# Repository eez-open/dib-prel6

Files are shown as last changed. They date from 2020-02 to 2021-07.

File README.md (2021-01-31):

### Ownership and License
The contributors are listed in CONTRIB.TXT. This project uses the TAPR v1.0 license, see LICENSE.TXT.

OSHW-HR000005 (https://certification.oshwa.org/hr000005.html)

### Description

The EEZ DIB PREL6 module features six independently programmable power relays.

### Feature list

* On-board STM32F030C6T6 or STM32F031C4T6 MCU
* 2 x 16-pin dual row 3.81 mm connectors
* 4 x SPDT relays, max. 8 A / 230 Vac
* 2 x SPST relays, max. 8 A / 230 Vac
* On-board +3.3 V LDO
* Firmware download via UART
* Optional SWD for debugging
* I2C EEPROM for storing board specific parameters
* Dimensions: 146 x 95 mm, 2-layer PCB

### Firmware repository

https://github.com/eez-open/dib-prel6-fw
The firmware download procedure is described in the User Manual in [Chapter 13](https://github.com/eez-open/modular-psu/blob/master/docs/user%20manual/EEZ%20BB3%20user%20manual.pdf). 

### r1B2 prototype

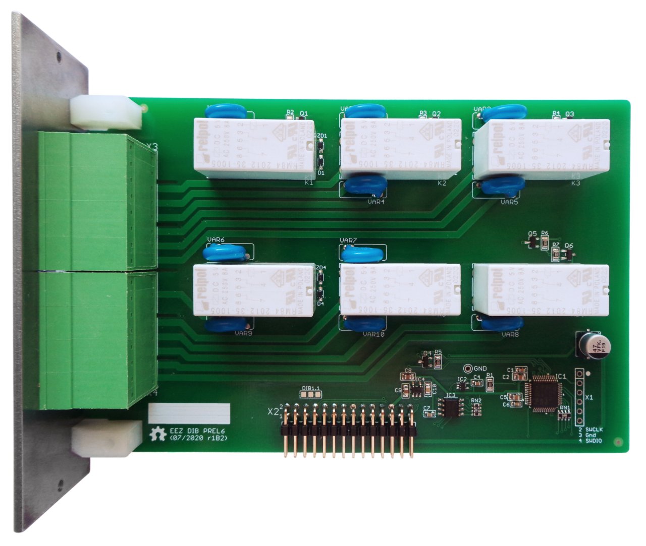
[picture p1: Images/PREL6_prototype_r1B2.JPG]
prototype


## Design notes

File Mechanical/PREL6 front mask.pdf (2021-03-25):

# PREL6

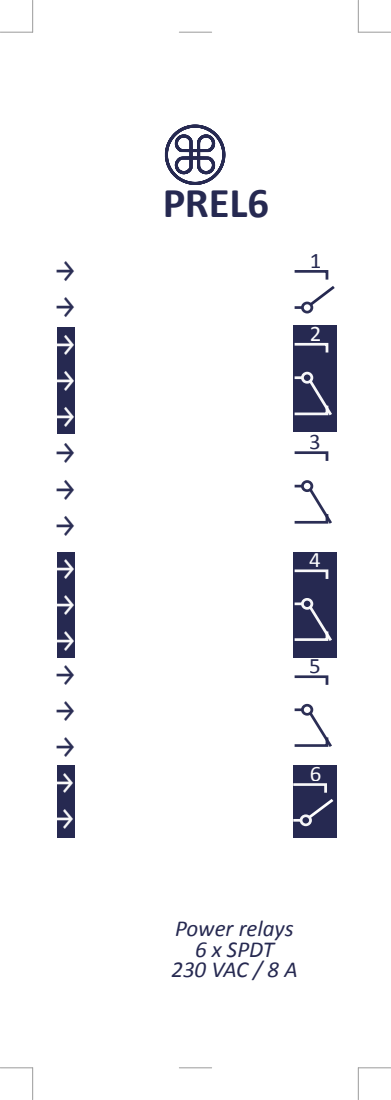
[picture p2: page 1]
Power relays 6 x SPDT 230 VAC / 8 A

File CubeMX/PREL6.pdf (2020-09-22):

## PREL6 Project Configuration Report

# 1. Description

## 1.1. Project

Project Name | PREL6
Board Name | custom
Generated with: | STM32CubeMX 5.6.1
Date | 09/22/2020

## 1.2. MCU

MCU Series | STM32F0
MCU Line | STM32F0x0 Value Line
MCU name | STM32F030C6Tx
MCU Package | LQFP48
MCU Pin number | 48

# 2. Pinout Configuration

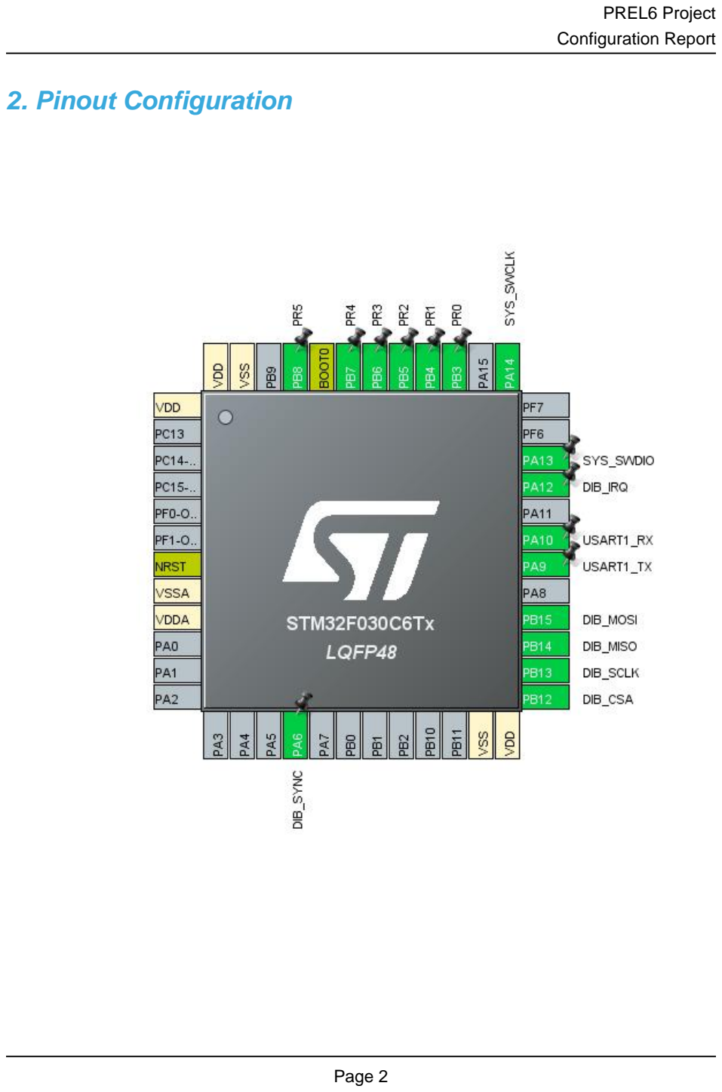
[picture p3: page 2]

# 3. Pins Configuration

Pin Number LQFP48 | Pin Name (function after reset) | Pin Type | Alternate Function(s) | Label
1 | VDD | Power
7 | NRST | Reset
8 | VSSA | Power
9 | VDDA | Power
16 | PA6 * | I/O | GPIO_Input | DIB_SYNC
23 | VSS | Power
24 | VDD | Power
25 | PB12 | I/O | SPI1_NSS | DIB_CSA
26 | PB13 | I/O | SPI1_SCK | DIB_SCLK
27 | PB14 | I/O | SPI1_MISO | DIB_MISO
28 | PB15 | I/O | SPI1_MOSI | DIB_MOSI
30 | PA9 | I/O | USART1_TX
31 | PA10 | I/O | USART1_RX
33 | PA12 * | I/O | GPIO_Output | DIB_IRQ
34 | PA13 | I/O | SYS_SWDIO
37 | PA14 | I/O | SYS_SWCLK
39 | PB3 * | I/O | GPIO_Output | PR0
40 | PB4 * | I/O | GPIO_Output | PR1
41 | PB5 * | I/O | GPIO_Output | PR2
42 | PB6 * | I/O | GPIO_Output | PR3
43 | PB7 * | I/O | GPIO_Output | PR4
44 | BOOT0 | Boot
45 | PB8 * | I/O | GPIO_Output | PR5
47 | VSS | Power
48 | VDD | Power

## * The pin is affected with an I/O function

# 4. Clock Tree Configuration

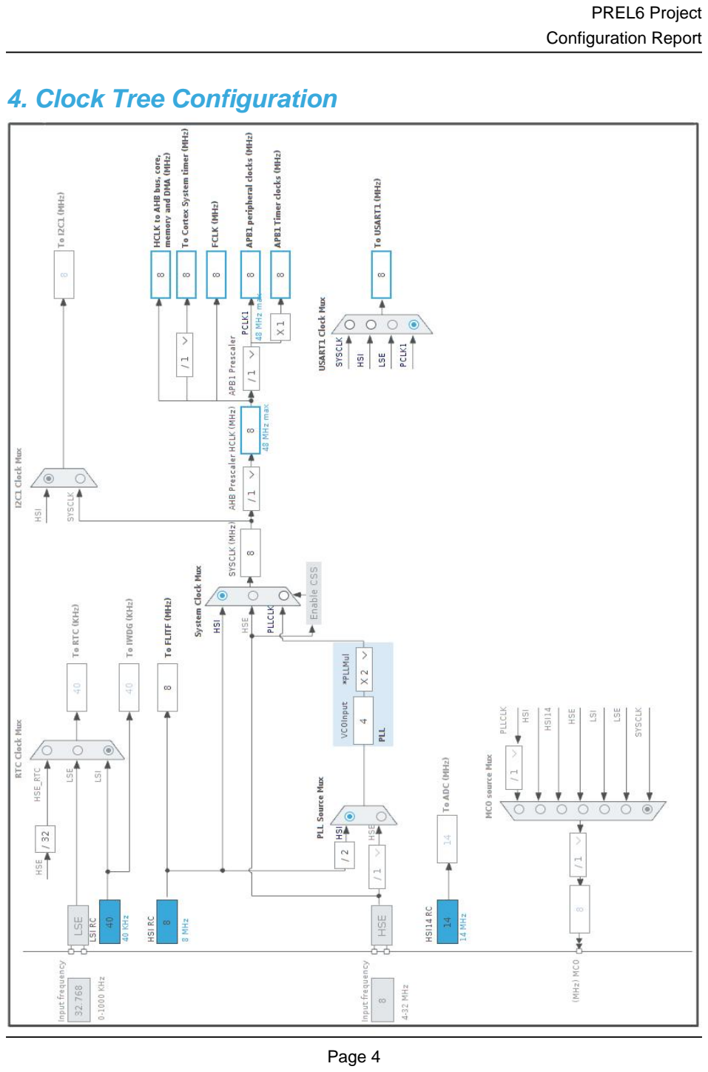
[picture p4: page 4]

# 5. Software Project

## 5.1. Project Settings

Name | Value
Project Name | PREL6
Project Folder | /home/denis/BACKUP/EEZ/Digital control/MCU/STM32/Projects/PREL6
Toolchain / IDE | EWARM V8.32
Firmware Package Name and Version | STM32Cube FW_F0 V1.11.0

## 5.2. Code Generation Settings

Name | Value
STM32Cube MCU packages and embedded software | Copy all used libraries into the project folder
Generate peripheral initialization as a pair of '.c/.h' files | No
Backup previously generated files when re-generating | No
Delete previously generated files when not re-generated | Yes
Set all free pins as analog (to optimize the power consumption) | No

# 6. Power Consumption Calculator report

### 6.1. Microcontroller Selection

Series | STM32F0
Line | STM32F0x0 Value Line
MCU | STM32F030C6Tx
Datasheet | 024849_Rev2

### 6.2. Parameter Selection

Temperature | 25
Vdd | 3.6

### 6.3. Battery Selection

Battery | Li-SOCL2(A3400)
Capacity | 3400.0 mAh
Self Discharge | 0.08 %/month
Nominal Voltage | 3.6 V
Max Cont Current | 100.0 mA
Max Pulse Current | 200.0 mA
Cells in series | 1
Cells in parallel | 1

## 6.4. Sequence

Step | Step1 | Step2
Mode | RUN | STOP
Vdd | 3.6 | 3.6
Voltage Source | Battery | Battery
Range | No Scale | No Scale
Fetch Type | FLASH | n/a
CPU Frequency | 48 MHz | 0 Hz
Clock Configuration | HSE PLL All IPs ON | Regulator_LP
Clock Source Frequency | 8 MHz | 0 Hz

### Peripherals

Additional Cons. | 0 mA | 0 mA
Average Current | 23.46 mA | 7.9 µA
Duration | 0.1 ms | 0.9 ms
DMIPS | 0.0 | 0.0
Ta Max | 100.36 | 105
Category | In DS Table | In DS Table

## 6.5. RESULTS

Sequence Time | 1 ms | Average Current | 2.35 mA
Battery Life | 1 month, 29 days, 16 hours | Average DMIPS | 0.0 DMIPS

## 6.6. Chart

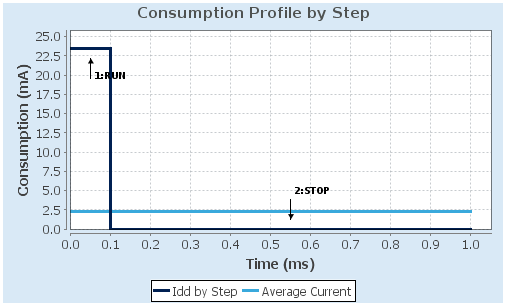
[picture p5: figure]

# 7. IPs and Middleware Configuration

# 7.1. CRC

## mode: Activated 7.1.1. Parameter Settings:

### Basic Parameters:

Default Polynomial State | Enable
Default Init Value State | Enable

### Advanced Parameters:

Input Data Inversion Mode | None
Output Data Inversion Mode | Disable
Input Data Format | Bytes

# 7.2. GPIO

# 7.3. SPI1

## Mode: Full-Duplex Slave Hardware NSS Signal: Hardware NSS Input Signal 7.3.1. Parameter Settings:

### Basic Parameters:

Frame Format | Motorola
Data Size | 4 Bits
First Bit | MSB First

### Clock Parameters:

Clock Polarity (CPOL) | Low
Clock Phase (CPHA) | 1 Edge

### Advanced Parameters:

CRC Calculation | Disabled
NSS Signal Type | Input Hardware

# 7.4. SYS

## mode: Debug Serial Wire Timebase Source: SysTick

# 7.5. USART1

## Mode: Asynchronous 7.5.1. Parameter Settings:

### Basic Parameters:

Baud Rate | 38400
Word Length | 8 Bits (including Parity)
Parity | None
Stop Bits | 1

### Advanced Parameters:

Data Direction | Receive and Transmit
Over Sampling | 16 Samples
Single Sample | Disable

### Advanced Features:

Auto Baudrate | Disable
TX Pin Active Level Inversion | Disable
RX Pin Active Level Inversion | Disable
Data Inversion | Disable
TX and RX Pins Swapping | Disable
Overrun | Enable
DMA on RX Error | Enable
MSB First | Disable

### * User modified value

# 8. System Configuration

# 8.1. GPIO configuration

IP | Pin | Signal | GPIO mode | GPIO pull/up pull down | Max Speed | User Label
SPI1 | PB12 | SPI1_NSS | Alternate Function Push Pull | No pull-up and no pull-down | High * | DIB_CSA
| PB13 | SPI1_SCK | Alternate Function Push Pull | No pull-up and no pull-down | High * | DIB_SCLK
| PB14 | SPI1_MISO | Alternate Function Push Pull | No pull-up and no pull-down | High * | DIB_MISO
| PB15 | SPI1_MOSI | Alternate Function Push Pull | No pull-up and no pull-down | High * | DIB_MOSI
SYS | PA13 | SYS_SWDIO | n/a | n/a | n/a
| PA14 | SYS_SWCLK | n/a | n/a | n/a
USART1 | PA9 | USART1_TX | Alternate Function Push Pull | No pull-up and no pull-down | High *
| PA10 | USART1_RX | Alternate Function Push Pull | No pull-up and no pull-down | High *
GPIO | PA6 | GPIO_Input | Input mode | No pull-up and no pull-down | n/a | DIB_SYNC
| PA12 | GPIO_Output | Output Push Pull | No pull-up and no pull-down | Low | DIB_IRQ
| PB3 | GPIO_Output | Output Push Pull | No pull-up and no pull-down | Low | PR0
| PB4 | GPIO_Output | Output Push Pull | No pull-up and no pull-down | Low | PR1
| PB5 | GPIO_Output | Output Push Pull | No pull-up and no pull-down | Low | PR2
| PB6 | GPIO_Output | Output Push Pull | No pull-up and no pull-down | Low | PR3
| PB7 | GPIO_Output | Output Push Pull | No pull-up and no pull-down | Low | PR4
| PB8 | GPIO_Output | Output Push Pull | No pull-up and no pull-down | Low | PR5

# 8.2. DMA configuration

DMA request | Stream | Direction | Priority
SPI1_RX | DMA1_Channel2 | Peripheral To Memory | Low
SPI1_TX | DMA1_Channel3 | Memory To Peripheral | Low

## SPI1_RX: DMA1_Channel2 DMA request Settings:

Mode: | Normal
Peripheral Increment: | Disable
Memory Increment: | Enable *
Peripheral Data Width: | Byte
Memory Data Width: | Byte

## SPI1_TX: DMA1_Channel3 DMA request Settings:

Mode: | Normal
Peripheral Increment: | Disable
Memory Increment: | Enable *
Peripheral Data Width: | Byte
Memory Data Width: | Byte

# 8.3. NVIC configuration

Interrupt Table | Enable | Preenmption Priority | SubPriority
Non maskable interrupt | true | 0 | 0
Hard fault interrupt | true | 0 | 0
System service call via SWI instruction | true | 0 | 0
Pendable request for system service | true | 0 | 0
System tick timer | true | 0 | 0
DMA1 channel 2 and 3 interrupts | true | 0 | 0
Flash global interrupt | unused
RCC global interrupt | unused
SPI1 global interrupt | unused
USART1 global interrupt | unused

### * User modified value

# 9. Predefined Views - Category view : Current

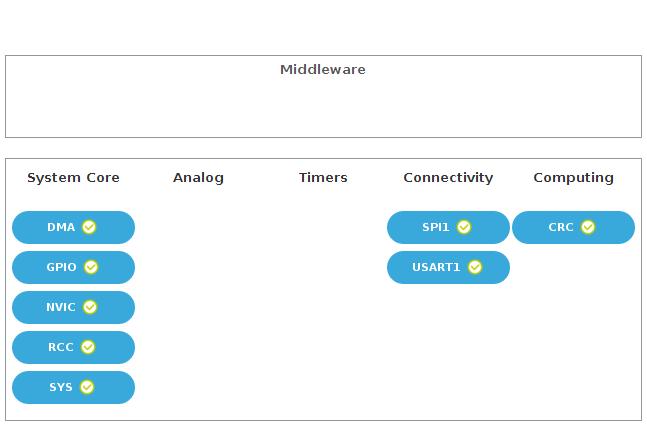
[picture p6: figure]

# 10. Software Pack Report

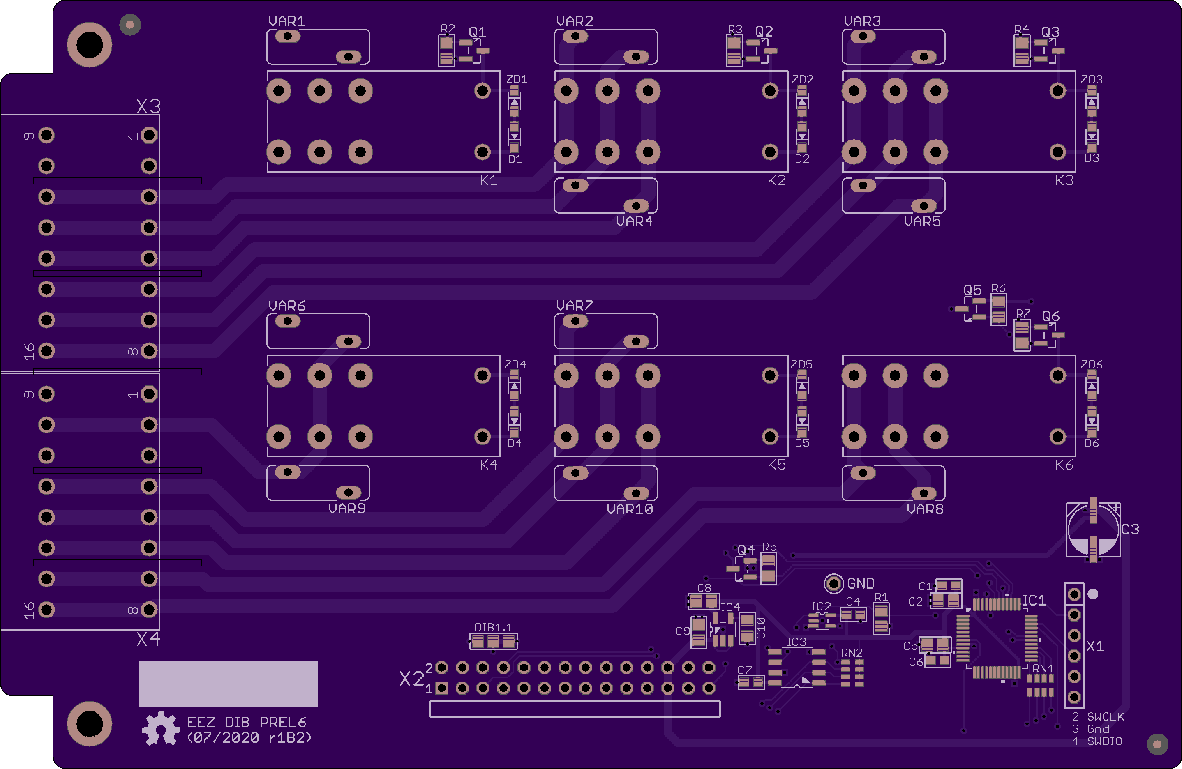
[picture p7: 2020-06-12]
Images/EEZ_DIB_PREL6_PCB_top.png

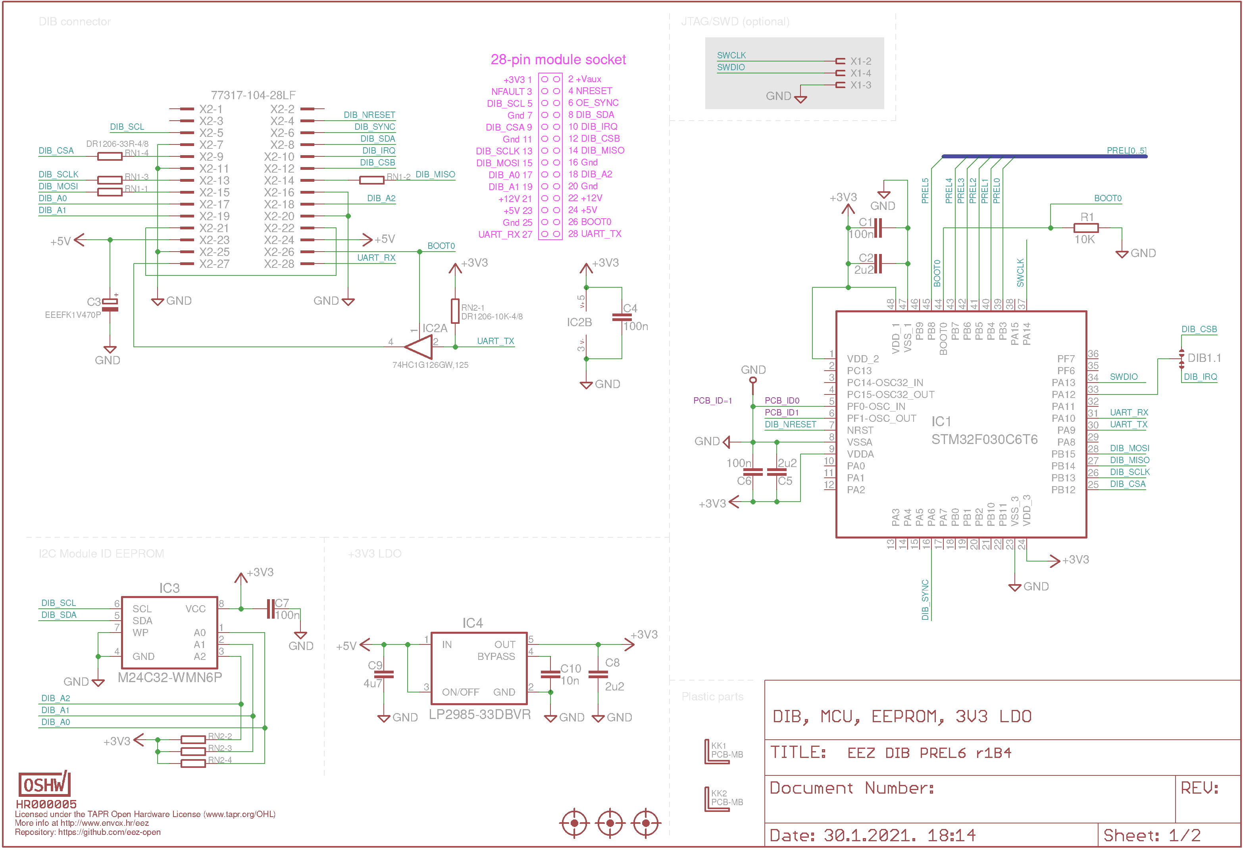
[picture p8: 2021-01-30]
EEZ DIB PREL6 r1B4 Sheet1of2.png

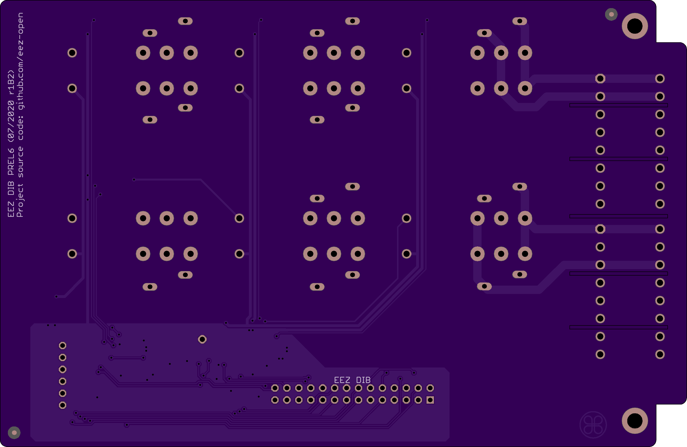
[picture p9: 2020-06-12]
Images/EEZ_DIB_PREL6_PCB_bottom.png

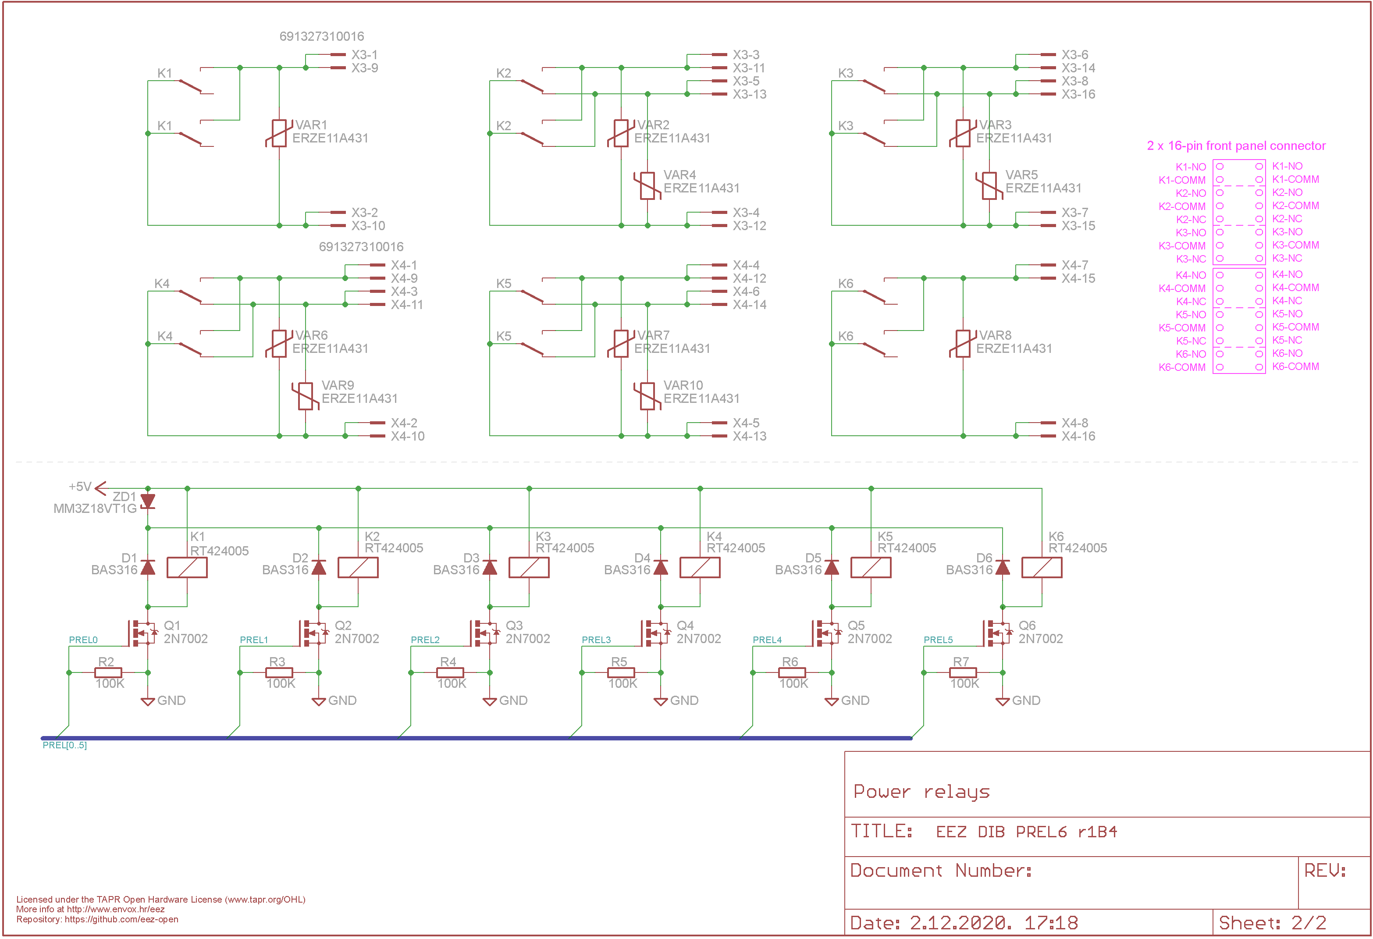
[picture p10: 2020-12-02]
EEZ DIB PREL6 r1B4 Sheet2of2.png

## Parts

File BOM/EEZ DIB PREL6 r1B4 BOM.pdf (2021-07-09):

EEZ DIB PREL6 BOM (r1B4, 2021-07-09) Project source code at https://github.com/eez-open/dib-prel6
Farnell / Element14 # Qty Part name Package Reference designator Code Part Number Unit price MOQ € | Digi-Key Part Number Unit price MOQ € | Mouser Part Number Unit price MOQ €
| | 80-C0603C104M4R
VJ0805Y103JXXP W1BC | | 710-885012207122
| | 80-C0805C225M4R ECLR
| | 667-EEE-FK1V470P
| | 963-TMK212AB7475 MG-T
1 | 4 100n | 0603 | C1, C4, C6, C7 | 2522597 | 0,011 10 | 490-4774-1-ND | 0,029 100 | 0,007 100
2 | 1 10n | 0805 | C10 | 2896555 | 0,065 10 | 490-7194-1-ND | 0,017 | 10 | 0,036 10
3 | 1 2u2 | 0805 | C2, C5, C8 | 1828829 | 0,198 | 5 | 1276-2954-1-ND | 0,085 | 10 | 0,078 10
4 | 1 EEEFK1V470P | C3 | 9695850 | EEEFK1V470P | 0,344 | 1 | PCE3842CT-ND | 0,312 | 10 | 0,238 10
5 | 1 4u7 | 0805 | C9 | 2112841 | 0,163 | 5 | 490-14466-1-ND | 0,114 | 10 | 0,104 10
6 | 6 BAS316 | SOD-323 | D1, D2, D3, D4, D5, D6 | 8734275 | BAS316,115 | 0,193 | 5 | 1727-7370-1-ND | 0,120 | 1 | 771-BAS316-T/R | 0,179 | 1
7 | 1 STM32F030C6T6 | | IC1 | 2393632 | STM32F030C6T6 | 1,350 | 1 | | 1,360 | 1 | | 1,360 | 1
8 | 1 74HC1G126GW.125 | TSSOP-5 | IC2 | - | 1727-6037-1-ND | 0,360 | 1 | 0,369 | 1
9 | 1 M24C32-WMN6P | SOIC-8 | IC3 | 1224413 | M24C32-WMN6P | 0,212 | 5 | - | 0,210 | 1
10 | 1 | SOT-23-5 | IC4 | 1053660 | 0,610 | 1 | 296-18476-1-ND | 0,540 | 1 | 0,507 | 1
11 | 6 RT424005 | K1, K2, K3, K4, K5, K6 | 1629052 | RT424005 | 2,640 | 1 | PB1998-ND | 3,620 | 1 | 655-RT424005 | 2,820 | 1
12 | 6 2N7002 | SOT-23 | Q1, Q2, Q3, Q4, Q5, Q6 | 1713825 | 2N7002K-7 | 0,148 | 5 | 0,126 | 10 | 0,113 10
13 | 1 10K | 0805 | R1 | 9237755 | 0,022 10 | 0,039 | 10 | 0,014 10
14 | 6 100K | 0805 | R2, R3, R4, R5, R6, R7 | 2447551 | 0,010 10 | 0,024 | 10 | 0,040 10
15 | 1 DR1206-33R-4/8 | RN1 | 1770128 | CAY16-330J4LF | 0,069 10 | 0,090 | 1 | 0,085 | 1
16 | 1 DR1206-10K-4/8 | RN2 | 1770137 | CAY16-103J4LF | 0,031 10 | 0,058 | 10 | 0,021 10
17 | 10 ERZE11A431 | 2291831 | ERZE11A431 | 0,459 10 | P16688-ND | 0,386 | 10 | 0,324 10
18 | 1 77317-104-28LF | X2 | - | | | | S2111EC-14-ND | 1,030 | 1 | | 1,540 | 1
19 | 2 691327310016 | X3, X4 | 1793077 | | 5,770 | 1 | | 7,810 | 1 | 651-1843130 | 9,270 | 1
20 | 1 MM3Z18VT1G | SOD-323 | ZD1 | 1431193 | MM3Z18VT1G | 0,109 10 | 0,103 | 10 | 0,108 10

C0603C104K4RAC
7081

GRM21BR71C225
KA12L

EMK212B7475KG-T

STM32F030C6T 6TR | 511-STM32F030C6T 6
Option: 2849912 STM32F031C4T6 2,510 1 STM32F031C4T6 | 497-13617-ND 2,200 | STM32F031C4T 2,110 1 6
| | 771-HC1G126GW125
| | 511-M24C32-WMN6P
| | 595-LP2985-33DBVR

THT; 8A relay
| T2N7002AKLMC T-ND | 757-T2N7002AKLM
RC0805FR-0710KL | 311-10.0KCRCT-ND | 603-RC0805FR-0710KL
| RMCF0805FT10 0KCT-ND | 71-CRCW0805100K FKEAC
1206 resistor array | CAY16-330J4LFCT-ND | 652-CAY16-330J4LF
| 103J4LFCT-ND | 652-CAY16-103J4LF
THT, varistor, Ø13mm VAR1, VAR2, VAR3, VAR4, VAR5, VAR6, VAR7, VAR8, VAR9, VAR10 | | 667-ERZ-E11A431
| | 649-77317-104-28LF
THT, 16-pin 3.81mm terminal MCD 1,5/ 8-G1-block header, male pins 3,81 | 732-691327310016-ND
LP2985-33DBVR | LP2985A- 33DBVTE4 .

MCWR08X1003FT
L
1206 resistor array | CAY16-

THT, 28-pin 0.1" header right angled

MM3Z18VT1GO
SCT-ND

863-
MM3Z18VT1G

Not installed

# Qty Part name | RS Components | TME | Price calculation for 1 set

Code Part Number Unit price MOQ € | Code / Part Number Unit price MOQ € | THT SMD

1 4 100n

2 1 10n

3 1 2u2

4 1 EEEFK1V470P

5 1 4u7

6 6 BAS316
7 1 STM32F030C6T6

8 1 74HC1G126GW.125

9 1 M24C32-WMN6P

10 1

11 6 RT424005
12 6 2N7002

13 1 10K

14 6 100K

15 1 DR1206-33R-4/8

16 1 DR1206-10K-4/8

17 10 ERZE11A431

18 1 77317-104-28LF

19 2 691327310016

20 1 MM3Z18VT1G

Option:
STM32F031C4T6

LP2985-33DBVR

Not installed

393-6952 | 0,069 25 | CL10B104KA8NNNC | 0,098 100 | 4 | Mouser | 0,007 € | 4 | 0,028
464-6672 | 0,026 50 | CC0805KRX7R9103 | 0,027 100 | 1 | Digikey | 0,017 € | 1 | 0,017
766-1031 | 0,069 100 | CL21B225KOFNNNG | 0,071 100 | 1 | RS | 0,069 € | 1 | 0,069
537-0657 EEEFK1V470P | 0,394 | 5 | EEEFK1V470P | 0,130 | 5 | 1 | TME | 0,130 € | 1 | 0,130
184-3708 | 0,062 50 | 0,242 10 | 1 | RS | 0,062 € | 1 | 0,062
397-2914 BAS316,115 | 0,122 50 | BAS316,115 | 0,026 25 | 6 | TME | 0,026 € | 6 | 0,159
| 0,972 | 5 | STM32F030C6T6 | 0,940 | 4 | 1 | TME | 0,940 € | 1 | 0,940
192-1080 | 2,152 | 5 | STM32F031C4T6 | 2,050 | 1
813-9282 | 0,024 100 | 74HC1G126GW.125 | 0,062 10 | 1 | RS | 0,024 € | 1 | 0,024
686-2453 | 0,180 25 | M24C32-WMN6P | 0,165 | 3 | 1 | TME | 0,165 € | 1 | 0,165
660-6733 LP2985-33DBVT | 0,737 | 1 | LP2985-33DBVR | 0,362 | 1 | 1 | TME | 0,362 € | 1 | 0,362
- | RT424005 | 1,150 | 5 | 6 | TME | 1,150 € | 6 | 6,900
671-0312 2N7002 | 1,250 20 | 2N7002LT1G | 0,019 25 | 6 | TME | 0,019 € | 6 | 0,115
125-1189 CRG0805F10K | 0,002 100 | RC0805FR-0710K | 0,022 100 | 1 | RS | 0,002 € | 1 | 0,002
223-0691 CRG0805F100K | 0,028 50 | 0805S8F1003T5E | 0,015 100 | 6 | Farnell | 0,010 € | 6 | 0,058
522-5670 CAY16-330J4LF | 0,004 50 | 4D03WGJ0330T | 0,009 100 | 1 | RS | 0,004 € | 1 | 0,004
522-5585 CAY16-103J4LF | 0,012 50 | 4D03WGJ0103T | 0,011 100 | 1 | TME | 0,011 € | 1 | 0,011
785-8904 ERZE11A431 | 0,265 25 | V275LA20AP | 0,180 | 5 | 10 | TME | 0,180 € 10 | 1,800
- | - | 1 | Digikey | 1,030 € | 1 | 1,030
191-1724 691327310016 | 7,900 | 1 | - | 2 | Farnell | 5,770 € | 2 | 11,540
802-4574 MM3Z18VT1G | 0,038 200 | MM3Z18VT1G | 0,025 25 | 1 | TME | 0,025 € | 1 | 0,025
19 | 33 | 23,44 €

Best
Supplier

Lowest
unit price
€

Order
Qty Line Cost €

VJ0603Y104KXJ
AT
08055C103KAT
2A
CL21B225KAFN
NNF

TMK212ABJ475
KG-T

C0805C475K3RACAU
TO

STM32F030C6T
6TR

STM32F031C4T
6
74HC1G126GW,
125
M24C32-
WMN6P

Mouser
MOQ | MOQ | MOQ
Farnell / Element14 | Digi-Key
Qty | Part name | Package | Reference designator | Code | Part Number | Unit price €
Part Number | Unit price
€

Part Number Unit price
€
1 N.C. | X1
2 PMB-1 | KK1, KK2 | - | - | -
4 TJ0831530000G | 2579776 | EBK-08-B | 2,400 | 1 | 609-3803-ND | 1,760 | 1 | 1,530 | 1

2 M3X4/D7985

2 M3X5/D965B

1 | -

Related parts and accessories PCB bracket; polyamide
8-pin 3.81mm pluggable
terminal block

649-220004-
D081B01LF
Screw; M3x4; cheese head;
Phillips

Module's studs mounting
(bottom), AC/DC mounting
frame (top), 3 x AC/DC
modules mounting
Screw; M3x5; countersunk;
Phillips; black finish

Module's studs mounting
(top), front and rear panel fixing, modules mounting on the front panel

Custom made components
PCB 2-layer 146 x 95
mm

All prices are net prices (without VAT)

Please note that BOM does not contain ordering number for parts on reels or that which includes re-reeling fee (e.g. Farnell). Take also into account that total cost is higher because min. quantity (MOQ) for many parts is larger then what is needed for single unit.

All resistors are 1% 0805 and all capacitors are X7R 0805 if not otherwise specified.

# Qty Part name | RS Components | TME | Price calculation for 1 set

Code Part Number Unit price MOQ € | Code / Part Number Unit price MOQ € | THT SMD

1 N.C.

2 PMB-1
4 TJ0831530000G

2 M3X4/D7985

2 M3X5/D965B

1

Related parts and accessories

Custom made components
PCB 2-layer 146 x 95
mm

Best
Supplier

Lowest
unit price
€

Order
| | | Qty | Line Cost €
1 | Farnell | 0,000 € | 1 | 0,000
- | PMB-1 | 0,072 10 | TME | 0,072 € | 2 | 0,145
- | 1,430 | 1 | TME | 1,430 € | 4 | 5,720
M3X4/D7985 | 0,012 100 | TME | 0,012 € | 2 | 0,023
M3X5/D965B | 0,012 100 | TME | 0,012 € | 2 | 0,025

5,91 €

JLCPCB | 6,244 € | 1 | 6,244
| | | 6,24 €

35,60 €

15EDGK-3.81-08P-14-
00A(H)

Total

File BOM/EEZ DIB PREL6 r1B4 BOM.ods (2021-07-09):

 |  |  |  |  | Farnell / Element14 |  |  |  | Digi-Key |  |  | Mouser |  |  | RS Components |  |  |  | TME |  |  |  |  | Price calculation for 1 set
# | Qty | Part name | Package | Reference designator | Code | Part Number | Unit price € | MOQ | Part Number | Unit price € | MOQ | Part Number | Unit price € | MOQ | Code | Part Number | Unit price € | MOQ | Code / Part Number | Unit price € | MOQ | THT | SMD | Best Supplier | Lowest unit price € | Order Qty | Line Cost €
1 | 4 | 100n | 0603 | C1, C4, C6, C7 | 2522597 | C0603C104K4RAC7081 | 0,011 | 10 | 490-4774-1-ND | 0,029 | 100 | 80-C0603C104M4R | 0,007 | 100 | 393-6952 | VJ0603Y104KXJAT | 0,069 | 25 | CL10B104KA8NNNC | 0,098 | 100 |  | 4 | Mouser | 0,007 € | 4 | 0,028
2 | 1 | 10n | 0805 | C10 | 2896555 | VJ0805Y103JXXPW1BC | 0,065 | 10 | 490-7194-1-ND | 0,017 | 10 | 710-885012207122 | 0,036 | 10 | 464-6672 | 08055C103KAT2A | 0,026 | 50 | CC0805KRX7R9103 | 0,027 | 100 |  | 1 | Digikey | 0,017 € | 1 | 0,017
3 | 1 | 2u2 | 0805 | C2, C5, C8 | 1828829 | GRM21BR71C225KA12L | 0,198 | 5 | 1276-2954-1-ND | 0,085 | 10 | 80-C0805C225M4RECLR | 0,078 | 10 | 766-1031 | CL21B225KAFNNNF | 0,069 | 100 | CL21B225KOFNNNG | 0,071 | 100 |  | 1 | RS | 0,069 € | 1 | 0,069
4 | 1 | EEEFK1V470P |  | C3 | 9695850 | EEEFK1V470P | 0,344 | 1 | PCE3842CT-ND | 0,312 | 10 | 667-EEE-FK1V470P | 0,238 | 10 | 537-0657 | EEEFK1V470P | 0,394 | 5 | EEEFK1V470P | 0,130 | 5 |  | 1 | TME | 0,130 € | 1 | 0,130
5 | 1 | 4u7 | 0805 | C9 | 2112841 | EMK212B7475KG-T | 0,163 | 5 | 490-14466-1-ND | 0,114 | 10 | 963-TMK212AB7475MG-T | 0,104 | 10 | 184-3708 | TMK212ABJ475KG-T | 0,062 | 50 | C0805C475K3RACAUTO | 0,242 | 10 |  | 1 | RS | 0,062 € | 1 | 0,062
6 | 6 | BAS316 | SOD-323 | D1, D2, D3, D4, D5, D6 | 8734275 | BAS316,115 | 0,193 | 5 | 1727-7370-1-ND | 0,120 | 1 | 771-BAS316-T/R | 0,179 | 1 | 397-2914 | BAS316,115 | 0,122 | 50 | BAS316,115 | 0,026 | 25 |  | 6 | TME | 0,026 € | 6 | 0,159
7 | 1 | STM32F030C6T6 |  | IC1 | 2393632 | STM32F030C6T6 | 1,350 | 1 | STM32F030C6T6TR | 1,360 | 1 | 511-STM32F030C6T6 | 1,360 | 1 |  | STM32F030C6T6TR | 0,972 | 5 | STM32F030C6T6 | 0,940 | 4 |  | 1 | TME | 0,940 € | 1 | 0,940
 |  | Option: STM32F031C4T6 |  |  | 2849912 | STM32F031C4T6 | 2,510 | 1 | 497-13617-ND | 2,200 |  | STM32F031C4T6 | 2,110 | 1 | 192-1080 | STM32F031C4T6 | 2,152 | 5 | STM32F031C4T6 | 2,050 | 1
8 | 1 | 74HC1G126GW.125 | TSSOP-5 | IC2 | - |  |  |  | 1727-6037-1-ND | 0,360 | 1 | 771-HC1G126GW125 | 0,369 | 1 | 813-9282 | 74HC1G126GW,125 | 0,024 | 100 | 74HC1G126GW.125 | 0,062 | 10 |  | 1 | RS | 0,024 € | 1 | 0,024
9 | 1 | M24C32-WMN6P | SOIC-8 | IC3 | 1224413 | M24C32-WMN6P | 0,212 | 5 | - |  |  | 511-M24C32-WMN6P | 0,210 | 1 | 686-2453 | M24C32-WMN6P | 0,180 | 25 | M24C32-WMN6P | 0,165 | 3 |  | 1 | TME | 0,165 € | 1 | 0,165
10 | 1 | LP2985-33DBVR | SOT-23-5 | IC4 | 1053660 | LP2985A-33DBVTE4 . | 0,610 | 1 | 296-18476-1-ND | 0,540 | 1 | 595-LP2985-33DBVR | 0,507 | 1 | 660-6733 | LP2985-33DBVT | 0,737 | 1 | LP2985-33DBVR | 0,362 | 1 |  | 1 | TME | 0,362 € | 1 | 0,362
11 | 6 | RT424005 | THT; 8A relay | K1, K2, K3, K4, K5, K6 | 1629052 | RT424005 | 2,640 | 1 | PB1998-ND | 3,620 | 1 | 655-RT424005 | 2,820 | 1 | - |  |  |  | RT424005 | 1,150 | 5 | 6 |  | TME | 1,150 € | 6 | 6,900
12 | 6 | 2N7002 | SOT-23 | Q1, Q2, Q3, Q4, Q5, Q6 | 1713825 | 2N7002K-7 | 0,148 | 5 | T2N7002AKLMCT-ND | 0,126 | 10 | 757-T2N7002AKLM | 0,113 | 10 | 671-0312 | 2N7002 | 1,250 | 20 | 2N7002LT1G | 0,019 | 25 |  | 6 | TME | 0,019 € | 6 | 0,115
13 | 1 | 10K | 0805 | R1 | 9237755 | RC0805FR-0710KL | 0,022 | 10 | 311-10.0KCRCT-ND | 0,039 | 10 | 603-RC0805FR-0710KL | 0,014 | 10 | 125-1189 | CRG0805F10K | 0,002 | 100 | RC0805FR-0710K | 0,022 | 100 |  | 1 | RS | 0,002 € | 1 | 0,002
14 | 6 | 100K | 0805 | R2, R3, R4, R5, R6, R7 | 2447551 | MCWR08X1003FTL | 0,010 | 10 | RMCF0805FT100KCT-ND | 0,024 | 10 | 71-CRCW0805100KFKEAC | 0,040 | 10 | 223-0691 | CRG0805F100K | 0,028 | 50 | 0805S8F1003T5E | 0,015 | 100 |  | 6 | Farnell | 0,010 € | 6 | 0,058
15 | 1 | DR1206-33R-4/8 | 1206 resistor array | RN1 | 1770128 | CAY16-330J4LF | 0,069 | 10 | CAY16-330J4LFCT-ND | 0,090 | 1 | 652-CAY16-330J4LF | 0,085 | 1 | 522-5670 | CAY16-330J4LF | 0,004 | 50 | 4D03WGJ0330T | 0,009 | 100 |  | 1 | RS | 0,004 € | 1 | 0,004
16 | 1 | DR1206-10K-4/8 | 1206 resistor array | RN2 | 1770137 | CAY16-103J4LF | 0,031 | 10 | CAY16-103J4LFCT-ND | 0,058 | 10 | 652-CAY16-103J4LF | 0,021 | 10 | 522-5585 | CAY16-103J4LF | 0,012 | 50 | 4D03WGJ0103T | 0,011 | 100 |  | 1 | TME | 0,011 € | 1 | 0,011
17 | 10 | ERZE11A431 | THT, varistor, Ø13mm | VAR1, VAR2, VAR3, VAR4, VAR5, VAR6, VAR7, VAR8, VAR9, VAR10 | 2291831 | ERZE11A431 | 0,459 | 10 | P16688-ND | 0,386 | 10 | 667-ERZ-E11A431 | 0,324 | 10 | 785-8904 | ERZE11A431 | 0,265 | 25 | V275LA20AP | 0,180 | 5 | 10 |  | TME | 0,180 € | 10 | 1,800
18 | 1 | 77317-104-28LF | THT, 28-pin 0.1" header right angled | X2 | - |  |  |  | S2111EC-14-ND | 1,030 | 1 | 649-77317-104-28LF | 1,540 | 1 | - |  |  |  | - |  |  | 1 |  | Digikey | 1,030 € | 1 | 1,030
19 | 2 | 691327310016 | THT, 16-pin 3.81mm terminal block header, male pins | X3, X4 | 1793077 | MCD 1,5/ 8-G1-3,81 | 5,770 | 1 | 732-691327310016-ND | 7,810 | 1 | 651-1843130 | 9,270 | 1 | 191-1724 | 691327310016 | 7,900 | 1 | - |  |  | 2 |  | Farnell | 5,770 € | 2 | 11,540
20 | 1 | MM3Z18VT1G | SOD-323 | ZD1 | 1431193 | MM3Z18VT1G | 0,109 | 10 | MM3Z18VT1GOSCT-ND | 0,103 | 10 | 863-MM3Z18VT1G | 0,108 | 10 | 802-4574 | MM3Z18VT1G | 0,038 | 200 | MM3Z18VT1G | 0,025 | 25 |  | 1 | TME | 0,025 € | 1 | 0,025
 |  |  |  |  |  |  |  |  |  |  |  |  |  |  |  |  |  |  |  |  |  | 19 | 33 |  |  |  | 23,44 €
 |  | Not installed
 | 1 | N.C. |  | X1 |  |  |  |  |  |  |  |  |  |  |  |  |  |  |  |  |  |  | 1 | Farnell | 0,000 € | 1 | 0,000
 |  | Related parts and accessories
 | 2 | PMB-1 | PCB bracket; polyamide | KK1, KK2 | - |  |  |  | - |  |  | - |  |  | - |  |  |  | PMB-1 | 0,072 | 10 |  |  | TME | 0,072 € | 2 | 0,145
 | 4 | TJ0831530000G | 8-pin 3.81mm pluggable terminal block |  | 2579776 | EBK-08-B | 2,400 | 1 | 609-3803-ND | 1,760 | 1 | 649-220004-D081B01LF | 1,530 | 1 | - |  |  |  | 15EDGK-3.81-08P-14-00A(H) | 1,430 | 1 |  |  | TME | 1,430 € | 4 | 5,720
 | 2 | M3X4/D7985 | Screw; M3x4; cheese head; Phillips | Module's studs mounting (bottom), AC/DC mounting frame (top), 3 x AC/DC modules mounting |  |  |  |  |  |  |  |  |  |  |  |  |  |  | M3X4/D7985 | 0,012 | 100 |  |  | TME | 0,012 € | 2 | 0,023
 | 2 | M3X5/D965B | Screw; M3x5; countersunk; Phillips; black finish | Module's studs mounting (top), front and rear panel fixing, modules mounting on the front panel |  |  |  |  |  |  |  |  |  |  |  |  |  |  | M3X5/D965B | 0,012 | 100 |  |  | TME | 0,012 € | 2 | 0,025
 |  |  |  |  |  |  |  |  |  |  |  |  |  |  |  |  |  |  |  |  |  |  |  |  |  |  | 5,91 €
 |  | Custom made components
 | 1 | PCB 2-layer 146 x 95 mm |  | - |  |  |  |  |  |  |  |  |  |  |  |  |  |  |  |  |  |  |  | JLCPCB | 6,244 € | 1 | 6,244
 |  |  |  |  |  |  |  |  |  |  |  |  |  |  |  |  |  |  |  |  |  |  |  |  |  |  | 6,24 €
 |  |  | All prices are net prices (without VAT)
 |  |  |  |  |  |  |  |  |  |  |  |  |  |  |  |  |  |  |  |  |  |  |  |  |  | Total | 35,60 €
 |  |  | Please note that BOM does not contain ordering number for parts on reels or that which includes re-reeling fee (e.g. Farnell). Take also into account that total cost is higher because min. quantity (MOQ) for many parts is larger then what is needed for single unit.
 |  |  | All resistors are 1% 0805 and all capacitors are X7R 0805 if not otherwise specified.

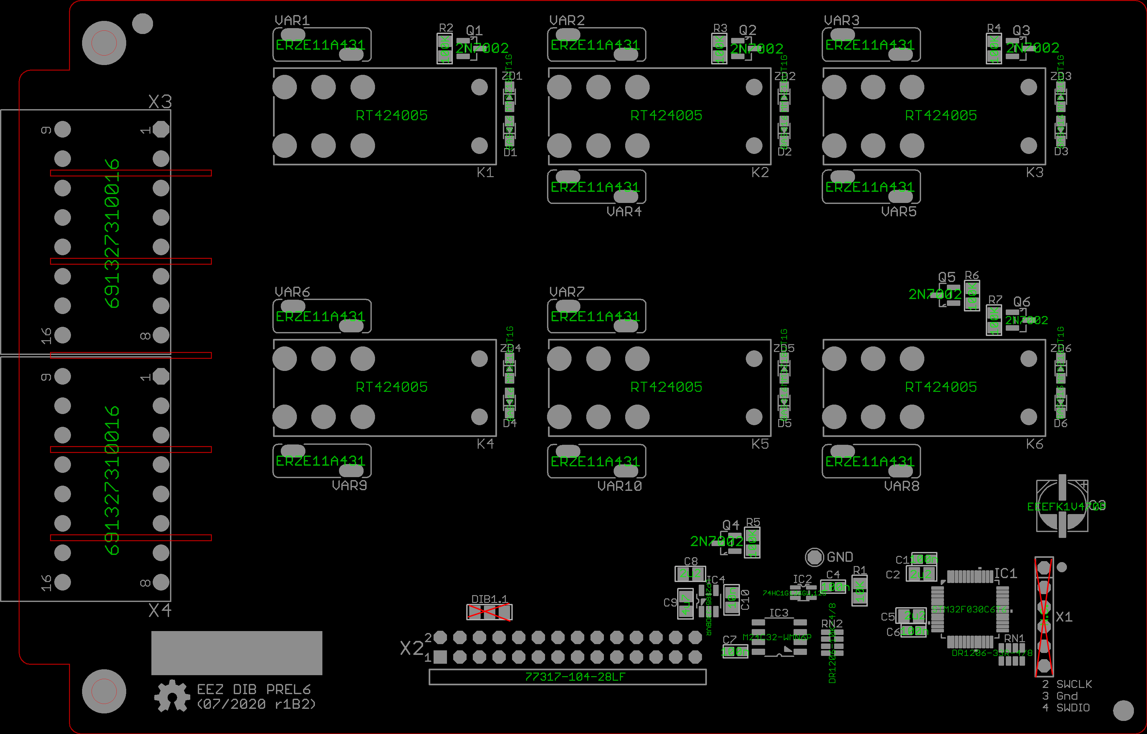
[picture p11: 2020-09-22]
Images/EEZ_DIB_PREL6_parts.png

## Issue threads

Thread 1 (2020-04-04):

VSSA and VDDA are swapped!

prasimix, 2020-04-04:
The analog power input to the MCU (IC1) is incorrectly connected.

prasimix, 2020-04-04:
Fixed

Closed 2020-04-04.

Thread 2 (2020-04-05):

BOOT0 wiring error

prasimix, 2020-04-05:
BOOT0 on X2 and IC2 is not properly wired.

prasimix, 2020-04-06:
Fixed

Closed 2020-04-06.

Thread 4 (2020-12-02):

Reduce number of zener diodes for relay clamping

prasimix, 2020-12-02:

prasimix, 2020-12-02:
fixed

Closed 2020-12-02.

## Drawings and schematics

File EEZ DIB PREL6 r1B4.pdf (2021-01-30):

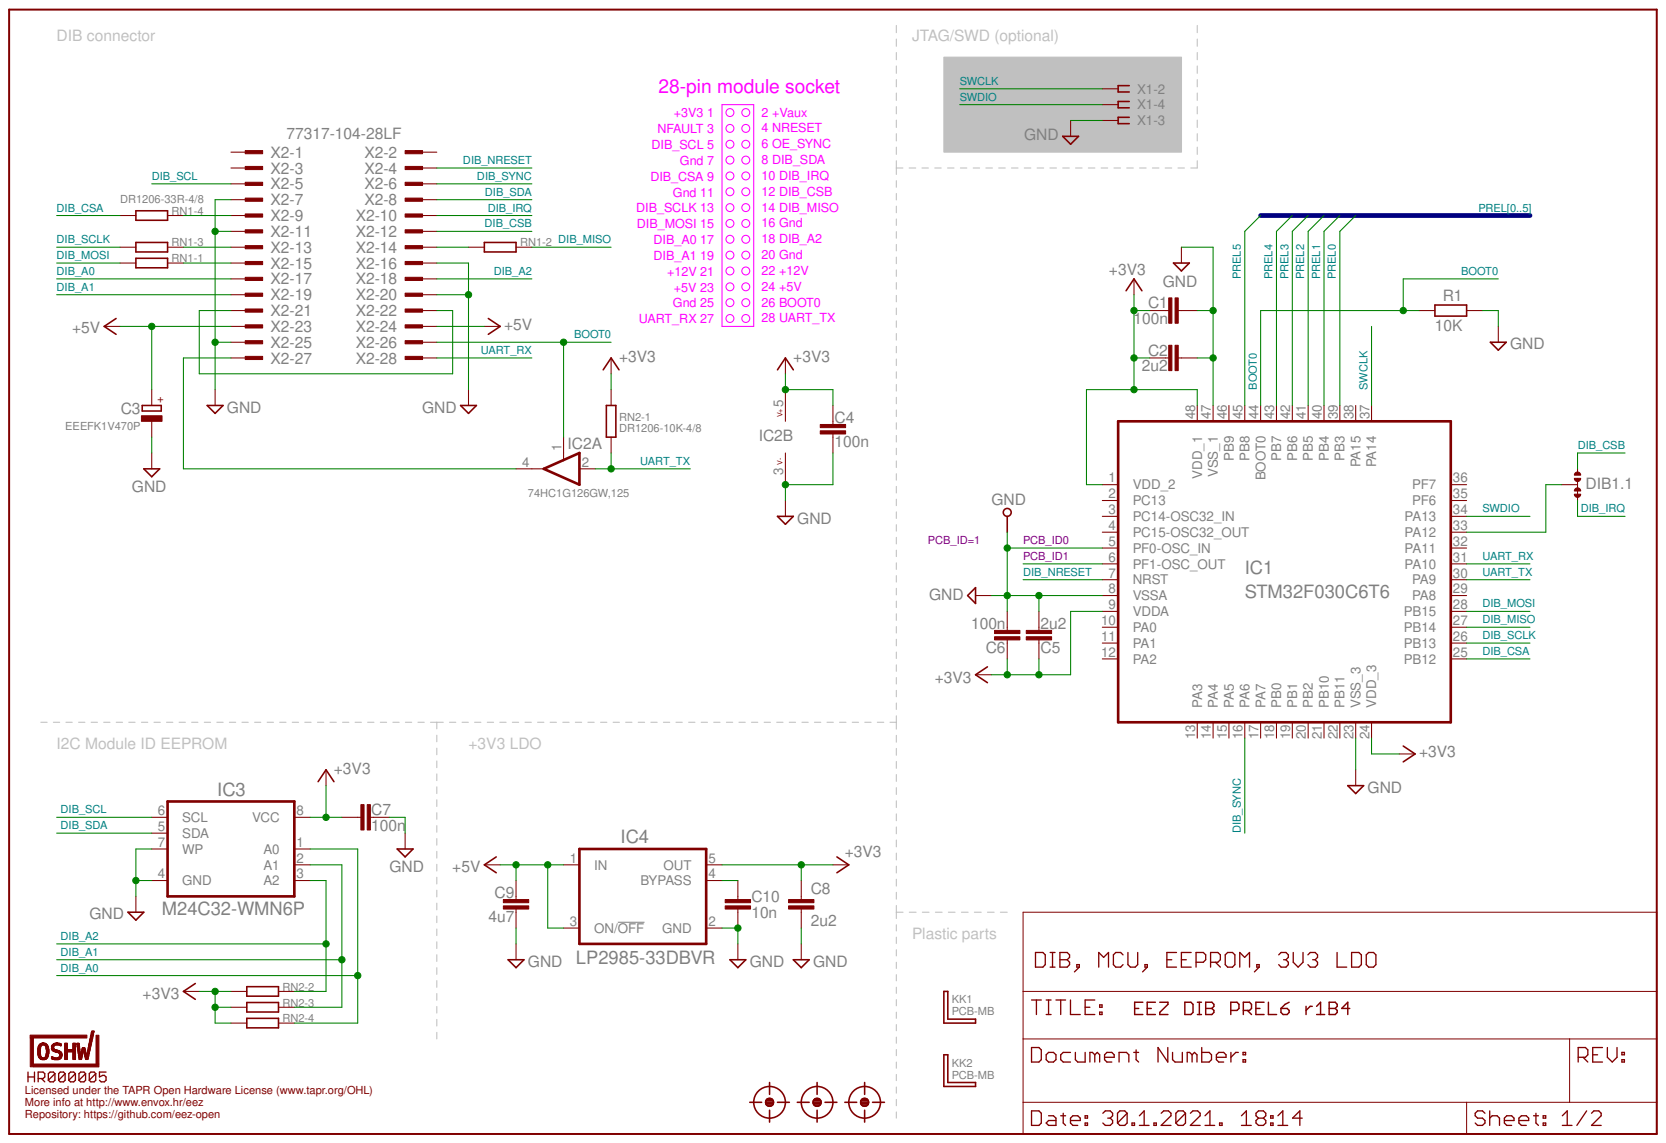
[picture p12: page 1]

Licensed under the TAPR Open Hardware License (www.tapr.org/OHL) Repository: https://github.com/eez-open More info at http://www.envox.hr/eez

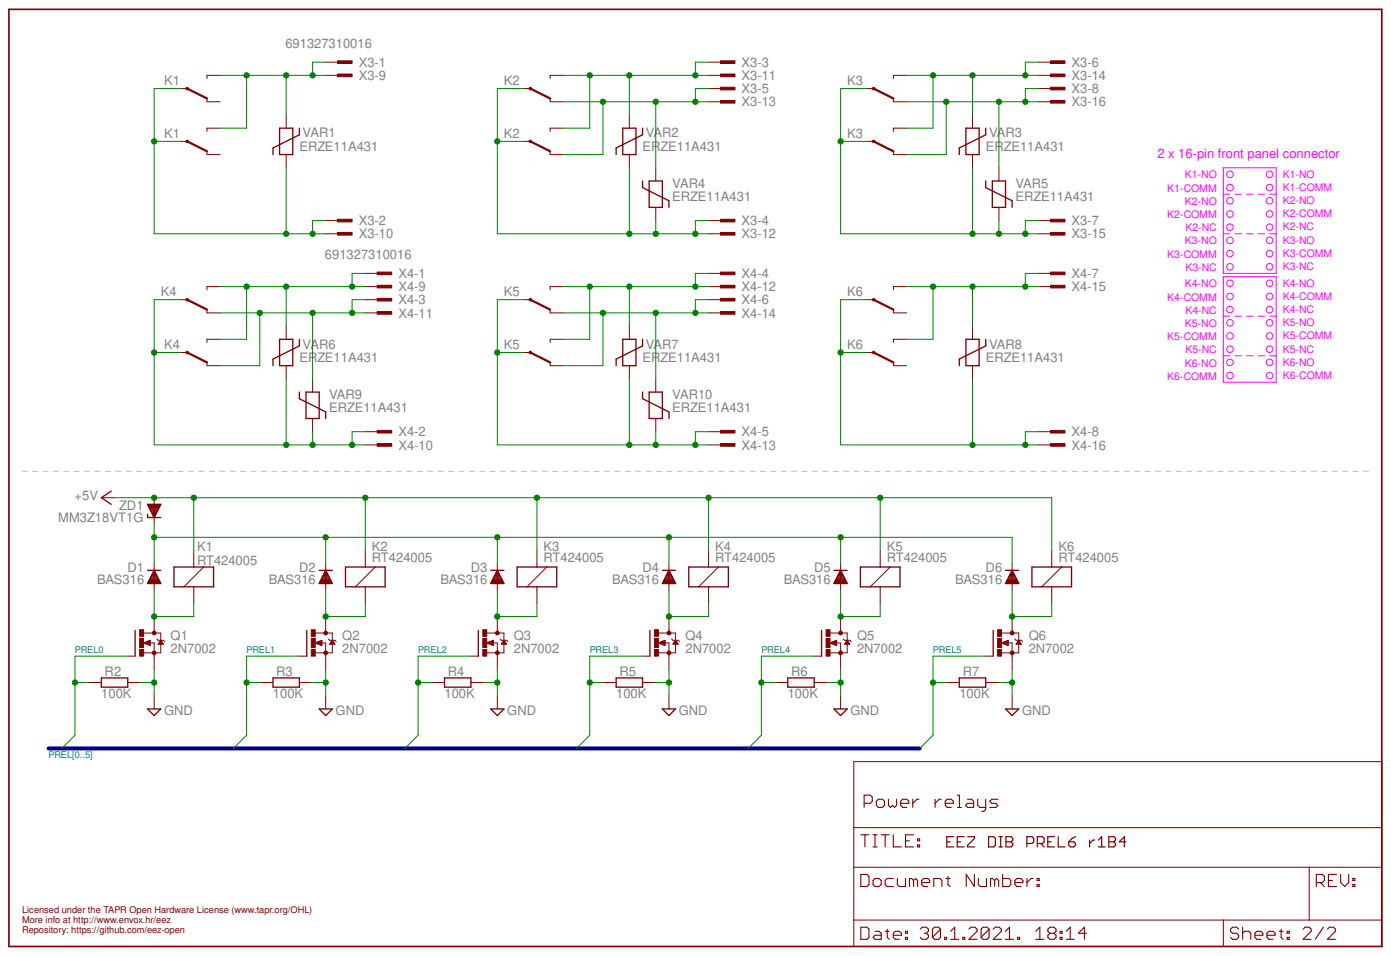
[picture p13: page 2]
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

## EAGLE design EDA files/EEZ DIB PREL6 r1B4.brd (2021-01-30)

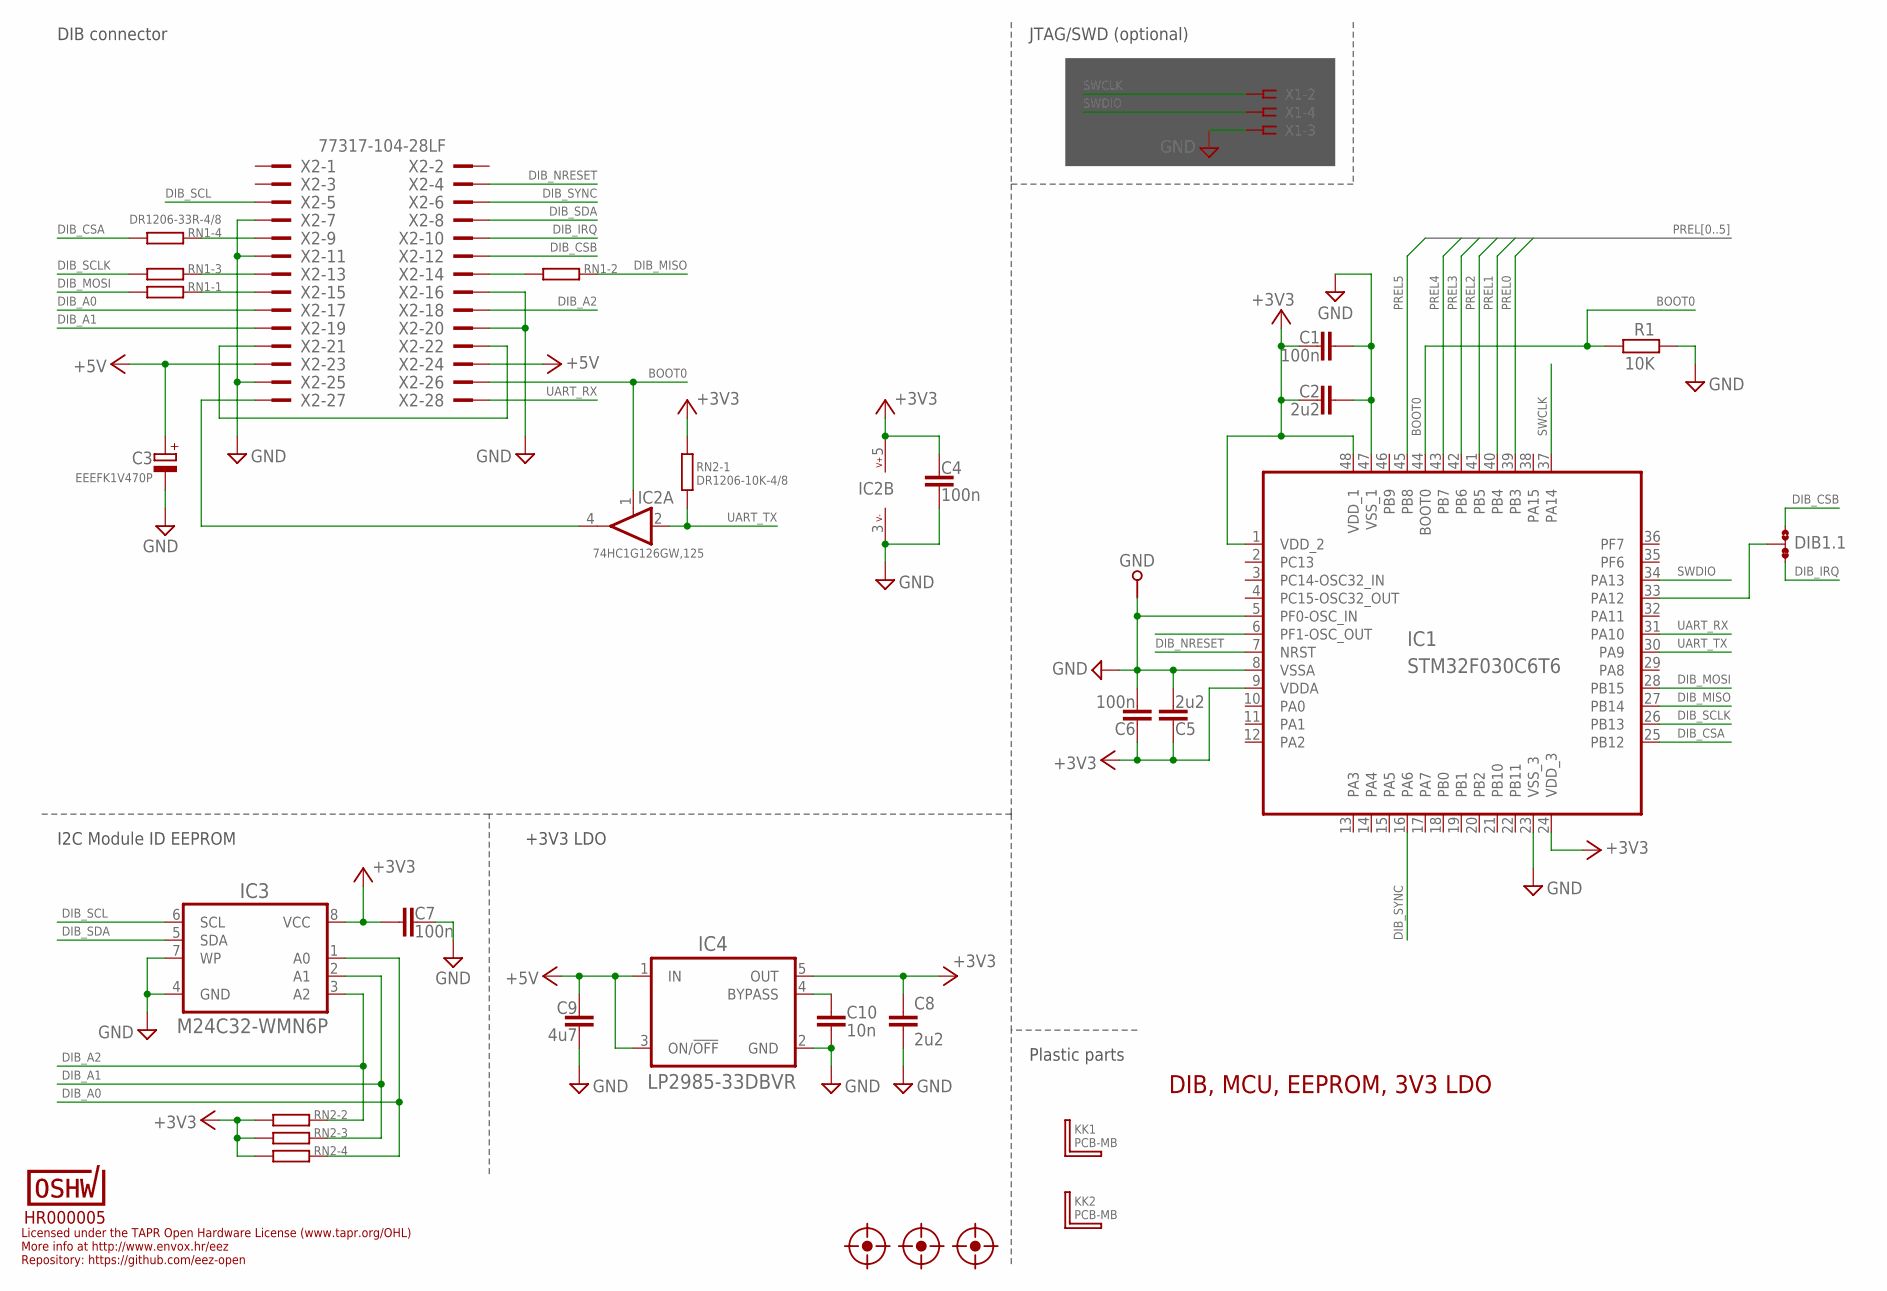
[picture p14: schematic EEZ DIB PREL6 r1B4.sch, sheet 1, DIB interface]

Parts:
C1, C4, C6, C7: 100n; C0603
C2, C5, C8: 2u2; C0805
C3: EEEFK1V470P; CAPAE660X610N
C9: 4u7; C0805
C10: 10n; C0805
DIB1.1: JP3-CUT-0805-ROTATED; JP3-0805-CUT2
FM1, FM2, FM3: FIDUCIAL_2; FIDUCIAL_DUAL
GND: PCB_TEST_TABSHIELD; PCB_SHIELD_TAB
IC1: STM32F030C6T6; LQFP-48
IC2: 74HC1G126GW,125; SOT65P210X110-5N
IC3: M24C32-WMN6P; SOIC127P600X173-8N
IC4: LP2985-33DBVR; SOT95P270X145-5N
KK1, KK2: PCB-MB
R1: 10K; R0805
RN1: DR1206-33R-4/8; CAY16
RN2: DR1206-10K-4/8; CAY16
U$3: HR000005; CERT-SMALL-SILK
X1: N.C.; SSW-106-02-S-S
X2: 77317-104-28LF

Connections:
+3V3: C1.2, C2.1, C4.1, C5.2, C6.1, C7.2, C8.1, IC1.1 (VDD_2), IC1.9 (VDDA), IC1.24 (VDD_3), IC1.48 (VDD_1), IC2.5 (V+), IC3.8 (VCC), IC4.5 (OUT), RN2.5 (2), RN2.6 (2), RN2.7 (2), RN2.8 (2)
+5V: C3.1 (+), C9.2, IC4.1 (IN), IC4.3 (ON/!OFF), X2.23, X2.24; also elsewhere on the board
BOOT0: IC1.44 (BOOT0), IC2.1 (EN), R1.2, X2.26
DIB_A0: IC3.1 (A0), RN2.4 (1), X2.17
DIB_A1: IC3.2 (A1), RN2.3 (1), X2.19
DIB_A2: IC3.3 (A2), RN2.2 (1), X2.18
DIB_CSA: IC1.25 (PB12), RN1.4 (1)
DIB_CSB: DIB1.1.NO, X2.12
DIB_IRQ: DIB1.1.NC, X2.10
DIB_MISO: IC1.27 (PB14), RN1.2 (1)
DIB_MOSI: IC1.28 (PB15), RN1.1
DIB_NRESET: IC1.7 (NRST), X2.4
DIB_SCL: IC3.6 (SCL), X2.5
DIB_SCLK: IC1.26 (PB13), RN1.3 (1)
DIB_SDA: IC3.5 (SDA), X2.8
DIB_SYNC: IC1.16 (PA6), X2.6
DIB_UART_RX: IC2.4 (O), X2.27
GND: C1.1, C2.2, C3.2 (-), C4.2, C5.1, C6.2, C7.1, C8.2, C9.1, C10.1, GND.1, IC1.5 (PF0-OSC_IN), IC1.8 (VSSA), IC1.23 (VSS_3), IC1.47 (VSS_1), IC2.3 (V-), IC3.4 (GND), IC3.7 (WP), IC4.2 (GND), R1.1, X1.3, X2.7, X2.11, X2.16, X2.20, X2.25; also elsewhere on the board
unnamed: X2.21, X2.22
unnamed: DIB1.1.COM, IC1.33 (PA12)
unnamed: RN1.5 (2), X2.9
unnamed: C10.2, IC4.4 (BYPASS)
unnamed: RN1.6 (2), X2.13
unnamed: RN1.7 (2), X2.14
unnamed: RN1.8 (2), X2.15
PREL0: IC1.39 (PB3); also elsewhere on the board
PREL1: IC1.40 (PB4); also elsewhere on the board
PREL2: IC1.41 (PB5); also elsewhere on the board
PREL3: IC1.42 (PB6); also elsewhere on the board
PREL4: IC1.43 (PB7); also elsewhere on the board
PREL5: IC1.45 (PB8); also elsewhere on the board
SWCLK: IC1.37 (PA14), X1.2
SWDIO: IC1.34 (PA13), X1.4
UART_RX: IC1.31 (PA10), X2.28
UART_TX: IC1.30 (PA9), IC2.2 (I), RN2.1

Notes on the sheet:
Licensed under the TAPR Open Hardware License (www.tapr.org/OHL)
Repository: https://github.com/eez-open
More info at http://www.envox.hr/eez
DIB, MCU, EEPROM, 3V3 LDO
Plastic parts
I2C Module ID EEPROM
+3V3 LDO
JTAG/SWD (optional)
DIB connector

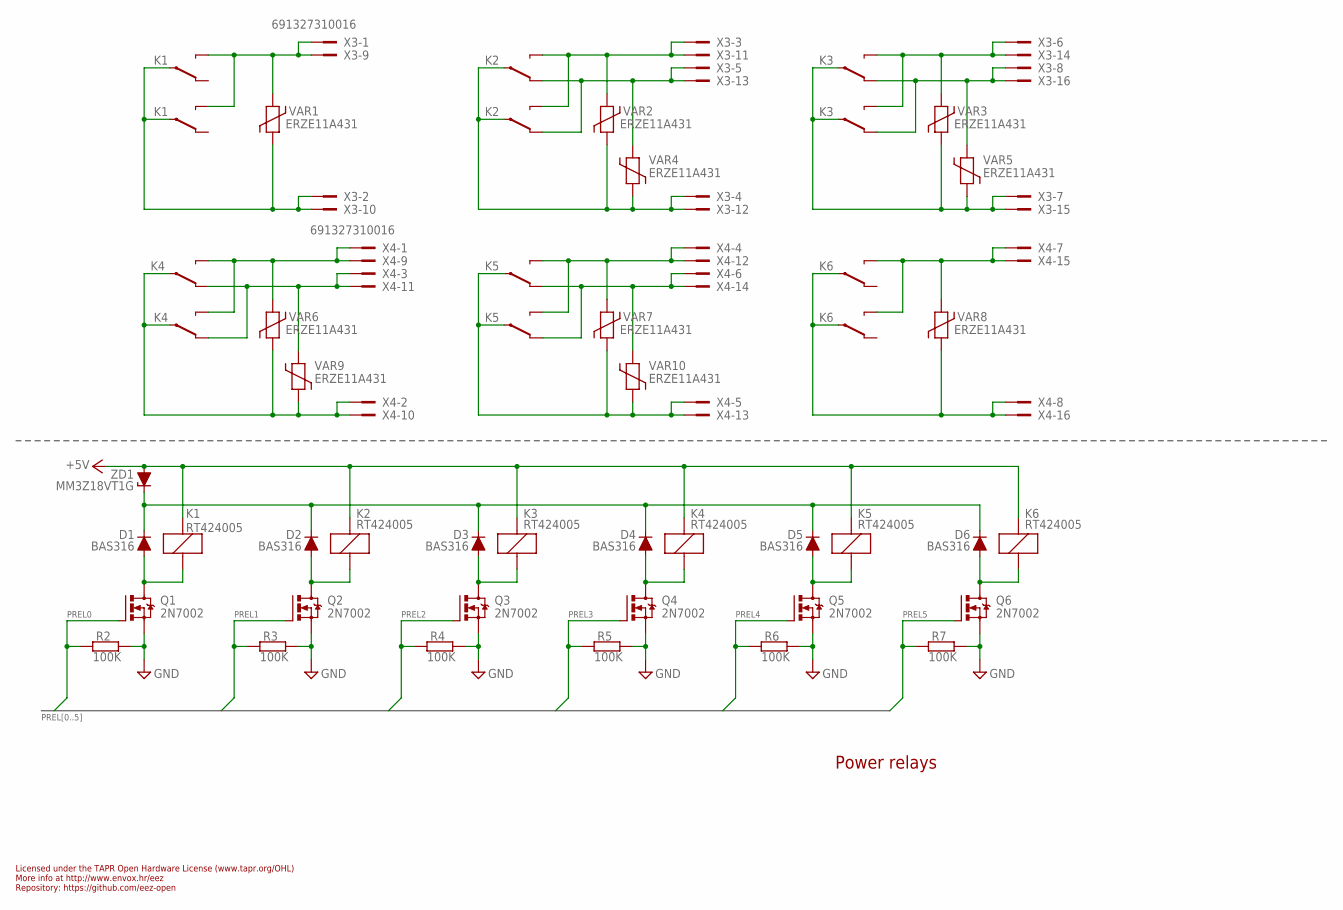
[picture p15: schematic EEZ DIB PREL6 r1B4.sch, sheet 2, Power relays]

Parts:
D1, D2, D3, D4, D5, D6: BAS316; SOD323-R
K1, K2, K3, K4, K5, K6: RT424005; RT-C/016A5_ROUND
Q1, Q2, Q3, Q4, Q5, Q6: 2N7002; SOT103P240X110-3N; MPN 2N7002-7-F
R2, R3, R4, R5, R6, R7: 100K; R0805
VAR1, VAR2, VAR3, VAR4, VAR5, VAR6, VAR7, VAR8, VAR9, VAR10: ERZE11A431; VARISTOR_13MM
X3, X4: 691327310016
ZD1: MM3Z18VT1G; SOD323-R

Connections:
+5V: K1.A2 (C1), K2.A2 (C1), K3.A2 (C1), K4.A2 (C1), K5.A2 (C1), K6.A2 (C1), ZD1.A; also elsewhere on the board
GND: Q1.2 (S), Q2.2 (S), Q3.2 (S), Q4.2 (S), Q5.2 (S), Q6.2 (S), R2.2, R3.2, R4.2, R5.2, R6.2, R7.2; also elsewhere on the board
unnamed: D4.A, K4.A1 (C2), Q4.3 (D)
unnamed: D1.A, K1.A1 (C2), Q1.3 (D)
unnamed: D1.C, D2.C, D3.C, D4.C, D5.C, D6.C, ZD1.C
unnamed: D2.A, K2.A1 (C2), Q2.3 (D)
unnamed: D3.A, K3.A1 (C2), Q3.3 (D)
unnamed: D5.A, K5.A1 (C2), Q5.3 (D)
unnamed: K4.12A (S), K4.12B (S), VAR9.2, X4.3, X4.11
unnamed: K4.14A (O), K4.14B (O), VAR6.2, X4.1, X4.9
unnamed: K5.12A (S), K5.12B (S), VAR10.2, X4.6, X4.14
unnamed: K4.11A, K4.11B, VAR6.1, VAR9.1, X4.2, X4.10
unnamed: K5.14A (O), K5.14B (O), VAR7.2, X4.4, X4.12
unnamed: K1.14A (O), K1.14B (O), VAR1.2, X3.1, X3.9
unnamed: K5.11A, K5.11B, VAR7.1, VAR10.1, X4.5, X4.13
unnamed: K6.14A (O), K6.14B (O), VAR8.2, X4.7, X4.15
unnamed: K1.11A, K1.11B, VAR1.1, X3.2, X3.10
unnamed: K6.11A, K6.11B, VAR8.1, X4.8, X4.16
unnamed: K2.14A (O), K2.14B (O), VAR2.2, X3.3, X3.11
unnamed: K2.11A, K2.11B, VAR2.1, VAR4.1, X3.4, X3.12
unnamed: K2.12A (S), K2.12B (S), VAR4.2, X3.5, X3.13
unnamed: K3.14A (O), K3.14B (O), VAR3.2, X3.6, X3.14
unnamed: K3.11A, K3.11B, VAR3.1, VAR5.1, X3.7, X3.15
unnamed: K3.12A (S), K3.12B (S), VAR5.2, X3.8, X3.16
unnamed: D6.A, K6.A1 (C2), Q6.3 (D)
PREL0: Q1.1 (G), R2.1; also elsewhere on the board
PREL1: Q2.1 (G), R3.1; also elsewhere on the board
PREL2: Q3.1 (G), R4.1; also elsewhere on the board
PREL3: Q4.1 (G), R5.1; also elsewhere on the board
PREL4: Q5.1 (G), R6.1; also elsewhere on the board
PREL5: Q6.1 (G), R7.1; also elsewhere on the board

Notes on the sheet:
Licensed under the TAPR Open Hardware License (www.tapr.org/OHL)
Repository: https://github.com/eez-open
More info at http://www.envox.hr/eez
Power relays

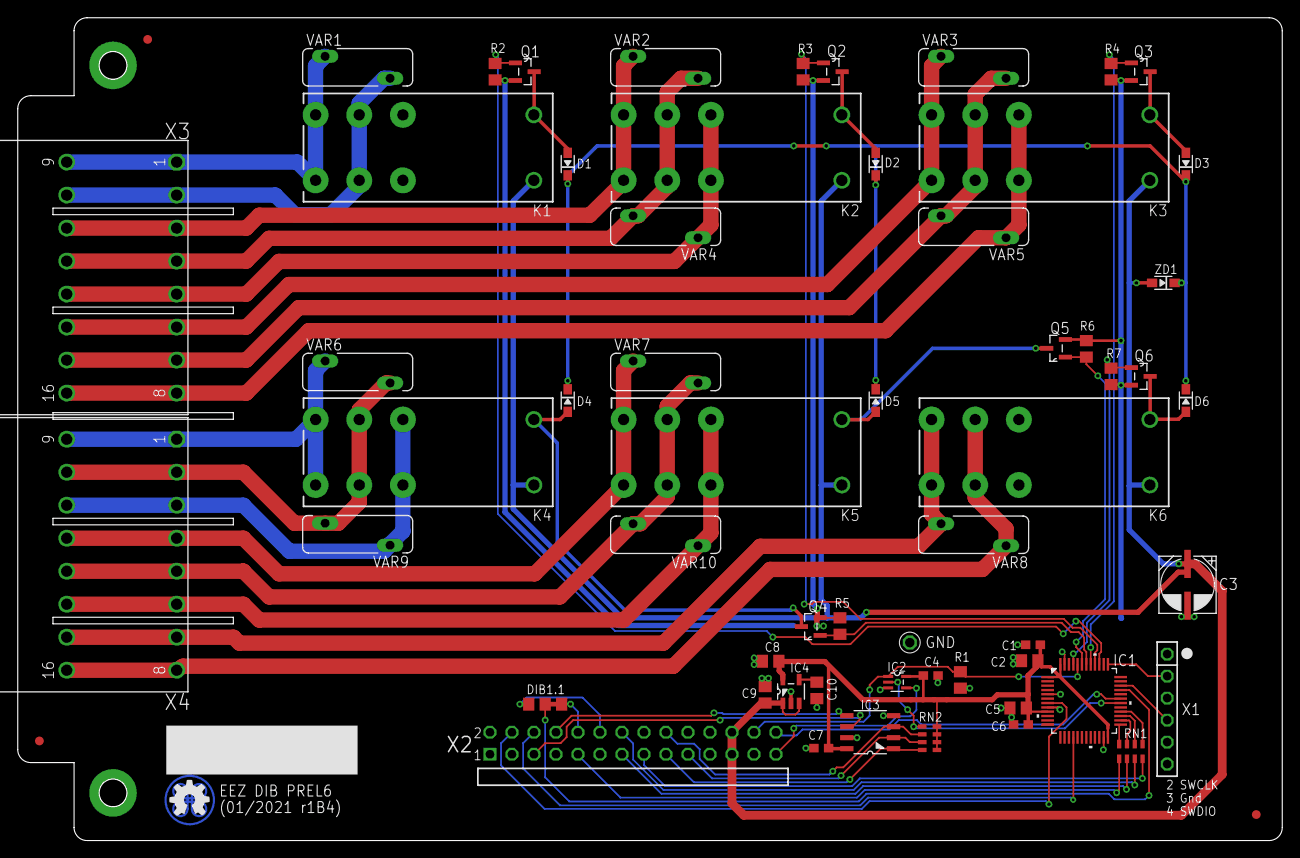
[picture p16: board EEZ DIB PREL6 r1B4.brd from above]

Board: 2 copper layers, 146.0 x 95.0 mm, 65 parts (1 on the bottom side), 58 nets.

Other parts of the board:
EEZ_SIGNATURE: SIGNATURESMALL; SIGNATURE_5MM

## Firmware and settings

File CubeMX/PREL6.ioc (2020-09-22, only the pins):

Mcu.UserName=STM32F030C6Tx
PA10.Signal=USART1_RX
PA12.GPIO_Label=DIB_IRQ
PA12.Signal=GPIO_Output
PA13.Signal=SYS_SWDIO
PA14.Signal=SYS_SWCLK
PA6.GPIO_Label=DIB_SYNC
PA6.Signal=GPIO_Input
PA9.Signal=USART1_TX
PB12.GPIO_Label=DIB_CSA
PB12.Signal=SPI1_NSS
PB13.GPIO_Label=DIB_SCLK
PB13.Signal=SPI1_SCK
PB14.GPIO_Label=DIB_MISO
PB14.Signal=SPI1_MISO
PB15.GPIO_Label=DIB_MOSI
PB15.Signal=SPI1_MOSI
PB3.GPIO_Label=PR0
PB3.Signal=GPIO_Output
PB4.GPIO_Label=PR1
PB4.Signal=GPIO_Output
PB5.GPIO_Label=PR2
PB5.Signal=GPIO_Output
PB6.GPIO_Label=PR3
PB6.Signal=GPIO_Output
PB7.GPIO_Label=PR4
PB7.Signal=GPIO_Output
PB8.GPIO_Label=PR5
PB8.Signal=GPIO_Output

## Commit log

2020-02-17 BOM added, improved PCB clearances
    [EEZ DIB PREL6 r1B1 BOM.ods, EEZ DIB PREL6 r1B1.brd, EEZ DIB PREL6 r1B1.sch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]
2020-02-22 UART relocated
    [EEZ DIB PREL6 r1B1.brd, EEZ DIB PREL6 r1B1.sch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]
2020-02-26 debug connector update
    [EEZ DIB PREL6 r1B1.brd, EEZ DIB PREL6 r1B1.sch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]
2020-02-28 PCB terminals position adjusted
    [EEZ DIB PREL6 r1B1.brd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]
2020-02-29 IC2 package update
    [EEZ DIB PREL6 r1B1.brd, EEZ DIB PREL6 r1B1.sch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]
2020-03-19 front panel connectors position adjusted
    [EEZ DIB PREL6 r1B1 BOM.ods, EEZ DIB PREL6 r1B1.brd, EEZ DIB PREL6 r1B1.sch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]
2020-04-04 #1 fixed
    [EEZ DIB PREL6 r1B1 BOM.ods, EEZ DIB PREL6 r1B2 BOM.ods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]
2020-05-04 swap UART TX and RX
    [EEZ DIB PREL6 r1B2.brd, EEZ DIB PREL6 r1B2.sch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]
2020-05-18 prototype picture
2020-06-12 IRQ selection jumper
    [EEZ DIB PREL6 r1B2.brd, EEZ DIB PREL6 r1B2.sch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]
2020-09-22 prototype r1B2 image
2020-12-02 #4, OSHW UID
    [EEZ DIB PREL6 r1B2 BOM.ods, EEZ DIB PREL6 r1B3_centroid.csv, EEZ DIB PREL6 r1B4 BOM.ods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]
2021-01-30 PCB ID added
    [EEZ DIB PREL6 r1B4.brd, EEZ DIB PREL6 r1B4.sch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]
2021-01-31 BOM update
    [EEZ DIB PREL6 r1B4 BOM.ods]
2021-03-25 Module front mask, centroid files
    [EEZ DIB PREL6 r1B4 BOM.ods, EEZ DIB PREL6 r1B4_centroid.csv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]

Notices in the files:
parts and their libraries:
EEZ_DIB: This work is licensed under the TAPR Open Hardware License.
